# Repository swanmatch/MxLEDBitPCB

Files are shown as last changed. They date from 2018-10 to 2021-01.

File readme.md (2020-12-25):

# 無限の可能性

[Cherry-Mx-Bitboard](https://github.com/ogatatsu/Cherry-Mx-Bitboard)を改変し、
helixを参考にSK6812miniがハマるようにしたものです。

自作キーボード用のプリント基板、１つの基板が１個のスイッチに対応しています。
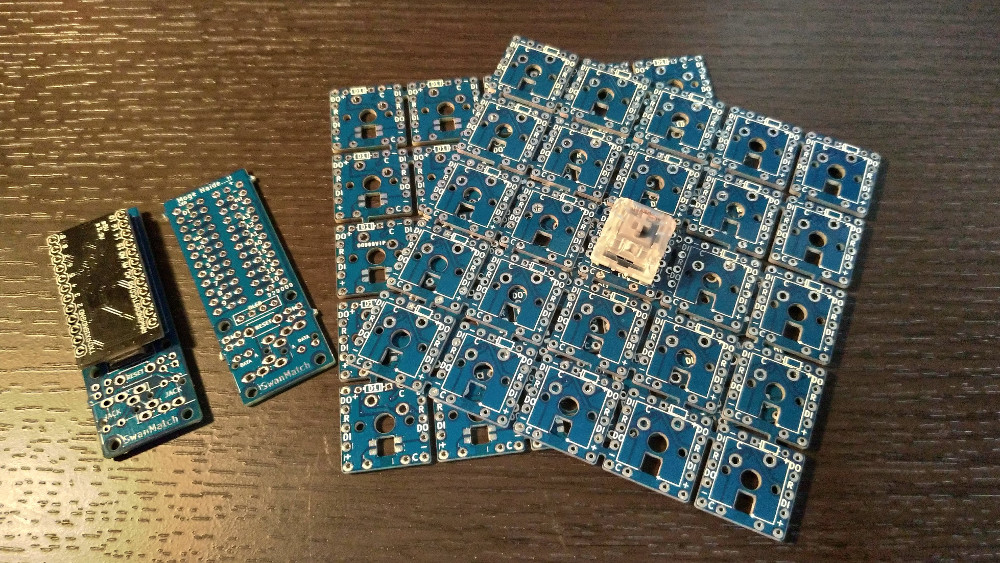
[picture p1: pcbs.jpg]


この基板を使うと、基板設計をしなくてもオリジナル配列のフルカラーバックライトのキーボードが作れます。

たとえば…！

example

詳しくは[こちら](https://swan-match.hatenablog.com/entry/2018/09/15/184923)。

[トッププレートの作り方](https://swanmatch.github.io/topplate_tips)を公開しました。

# Languages
* [Japanese](./readme.md)
* [English](./readme_en.md)
* [French](./readme_fr.md)
* [Russian](./readme_ru.md)
* [Chinese](./readme_zh.md)

## 無限の可能性シリーズ

### ProMicroのおうち

ProMicroのPinを取り出せるようにし、
OLED、リセットスイッチ、分割キーボード向けのTRRS、
そしてマウント用のM2ネジ穴を足したもの。  
TRRSのPinアサインはHelix互換。

### 無限の可能性シリーズ

無限の可能性には複数のシリーズがあり、それぞれ対応するLED,スイッチダイオードが違います。  
以下に仕様をまとめます。

プロジェクト | スイッチ | Kailhソケット利用可否 | LED | スルーホールダイオード | SOD-123 |
-|-|-|-|-|-
Nexus | MX | No | SK6812MINI | Yes | No |
Altana | MX | Yes | SK6812MINI | Yes | No |
Suxen | MX | No | YS-SK6812MINI | Yes | Yes(*) |
Container | MX | Yes | YS-SK6812MINI | Yes | Yes(*) |
Choc | KailhLowProfile | No | YS-SK6812MINI | No | Yes |

(*) スウェンとコンテナでSOD-123を使う場合、スペースの都合で片方のパッドをスルーホールの穴と共有することになるので、少しトリッキーな実装になります。

## 材料例(仕入先)

* 任意にカットしたプレート
  * 2mmアクリル板(遊舎工房さん)  
    3mmアクリル角材とアクリルサンデーなどの接着剤があるとよいです。(ホームセンター)
  * 3Dケース(DMM.make)
  * 5mmダンボール(そのへんから拾ってくるなど。)
* スイッチングダイオード1N4148、SOD-123(TALPKeyboardさん)
* SK6812mini、YS-SK6812MINI-E(遊舎工房さん)
* Kailhソケット(遊舎工房さん、Talpkeyboardさん、Kbdfansさん)
* ウレタンエナメル線(0.35～0.45mmくらいのものがオススメ。ホームセンタなどにもある。ビニル線でも可能ですが溶けちゃったり結構大変)
* TRRSジャック、RESETボタン(秋月電子さん)
* OLED(オプション、遊舎工房さん)
* Promicro(遊舎工房さん、TALPkeyboardさん)
* 各種スペーサー、ネジ(廣杉計器さん、Wilcoさんなど)
* キースイッチ、キーキャップ(お好みに応じて遊舎工房さん、TalpKeyboardさんなど)
* USBケーブル、TRS(3.5mm3極)ケーブル

その他に温度調節はんだごて、テスター、ピンセットなどの工具が必要です。

## Pinアサイン

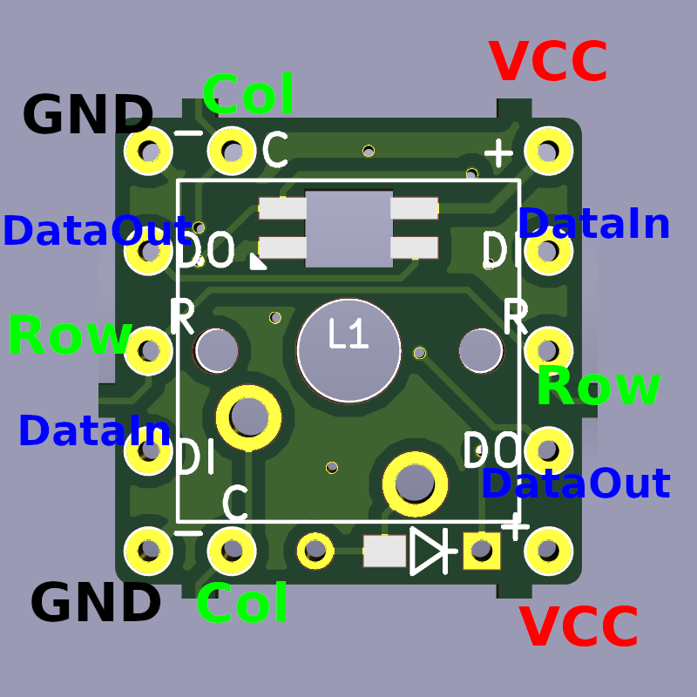
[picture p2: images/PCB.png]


無限の可能性のピン配置は以下の通りです。

* Ｃ: 横線(Col)
* Ｒ: 縦線(Row)
* DI: LED制御信号入力(DataIn)
* DO: LED制御信号出力(DataOut)
* －: グランド(LED用)
* ＋: VCC(LED用5V)

写真の例はSuxenですが、ほかもだいたい似たような感じです。

## 組立手順

1. SK6812miniをはんだ付けします。  
  温度調節はんだごてで220℃くらいではんだ付けしてください。  
  もたもたしていると壊れます。  
  はんだも融点200℃以下の低温はんだを使ってください。
2. ダイオードをはんだ付けします。
3. トッププレートにスイッチをはめて、裏に無限の可能性をはめてスイッチの足をはんだ付けします。(Altana,Containerはソケット)  
  このとき2mmアクリル板を使う場合は、スイッチが抜けてしまうのを防ぐため、
  プレート裏面のスイッチ脇に3mmアクリル角材をアクリル接着剤などでくっつけておくこといいです。
4. 自身の組みたいキーボードのキーマトリックスに合わせ、横線(Col)と縦線(Row)を配線します。
5. 全ての「－」と「＋」をつなげる。
6. LEDの光らせたい順番にDIからDOに数珠つなぎに配線していきます。
  一個目DO→二個目DI→二個目DO→三個目DI…
7. TRRSJACKとRESETスイッチをはんだ付けします。
8. OLEDソケットをはんだ付けします。
9. 任意のピンの横の穴からColとRow、LED(DO)、GND、VCCをそれぞれ無限の可能性に対して配線します。
10. Promicroをソケットにはんだ付けします。  
  (コンスルーを使ってもいいですが、もげたらソケットごと交換したほうが安上がり。)
11. お好みに合わせてファームウェアを作成して書き込んで完成。  
  ファームウェアは[QMK_Firmware](https://github.com/qmk/qmk_firmware)を使うととても簡単です。  
  参考: [自作キーボードのファームウェアを用意する手段3種類](https://skyhigh-works.hatenablog.com/entry/2018/10/09/120909)

## 配線例

例えばSuxenで下記のような配列の場合、以下のような配線になります。  
ウレタンエナメル線(UEW)は被膜を剥がすのが結構大変なので、
ショートの可能性が少ない隣り合う基板間の配線は、
切り落としたダイオードの足がオススメです。  

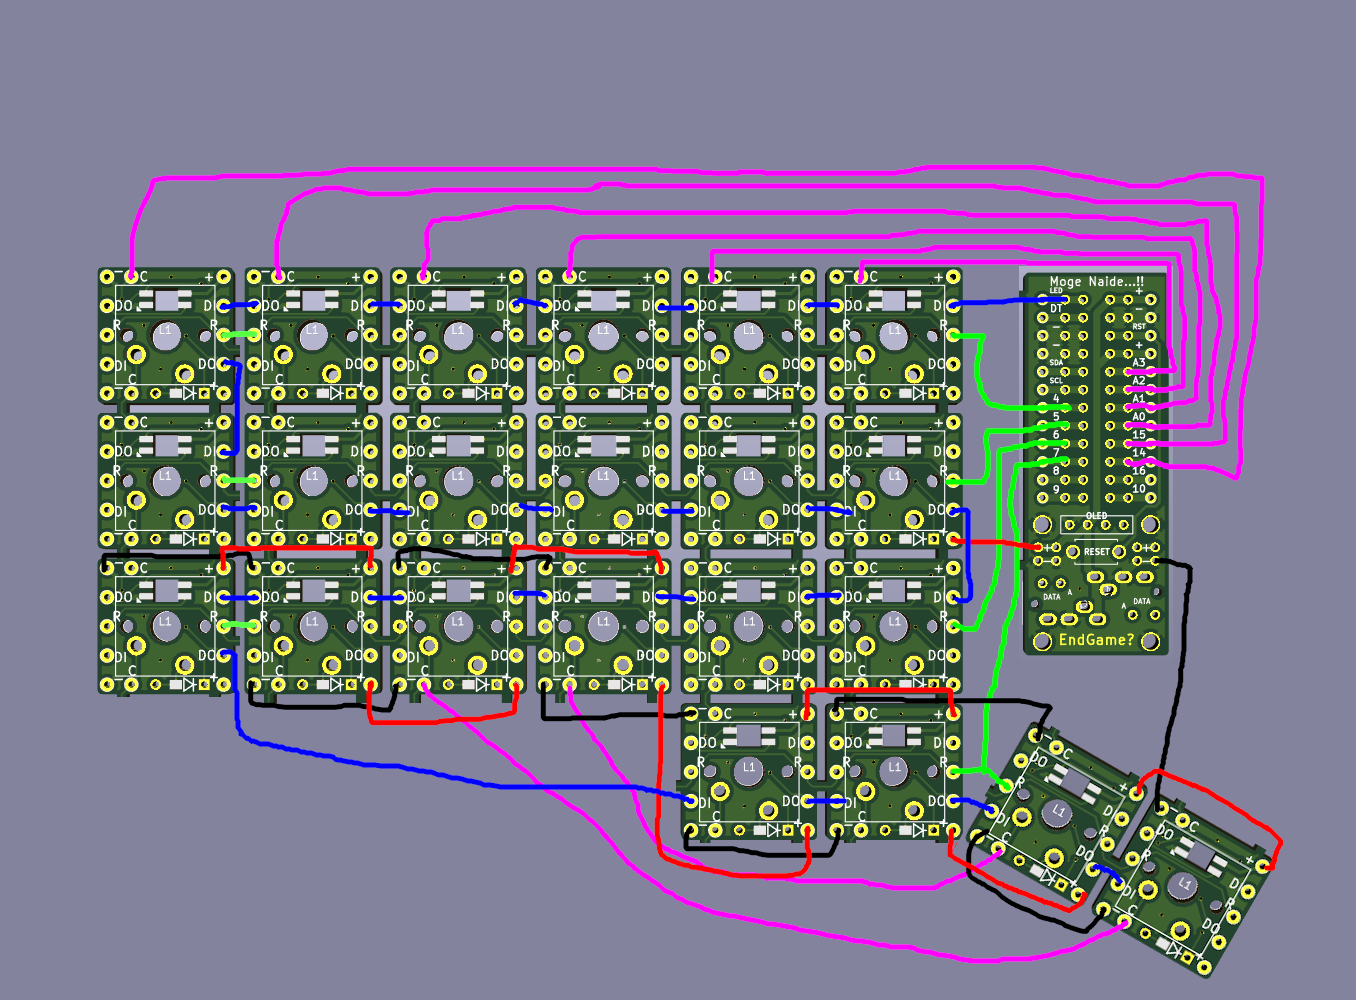
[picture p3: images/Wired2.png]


### 注意事項

* Altana、ContainerはKailhソケットを使ってスイッチを交換できるバージョンです。
* Suxen、ContainerはYS-SK6812MINIに対応していて、LEDの欠けている足をPCBの三角のシルクに合わせて実装してください。
* もしも万が一やんごとなき事情で、どうしてもLEDを光らせる必要がない場合、
  ColとRowだけ配線すればキーボードとして機能します。[配線例](./images/Wired.png)
* 国内でよく採用されている、サンドイッチマウントのキーボードの場合、
  トッププレートとボトムプレートをスペーサーで配置しますが、
  無限の可能性の場合キーの間にスペーサーが入る隙間がありません。
  キーの外側にネジ穴を設けてください。
* 「おうち」は、先にPromicroをはんだ付けしてしまうと、
  無限の可能性側と配線する際に、ハンダがホールからもれて、
  Promicro本体の部品をショートさせてしまう場合があります。  
  Promicroは最後にはんだ付けするようにしてください。

## 終わりに

この基板を使ってキーボードを組んだ際にはぜひ[@swan_match](https://twitter.com/swan_match)までご一報ください。

あなたのEndGameを応援しています！！

## Licence

https://creativecommons.org/licenses/by/4.0/

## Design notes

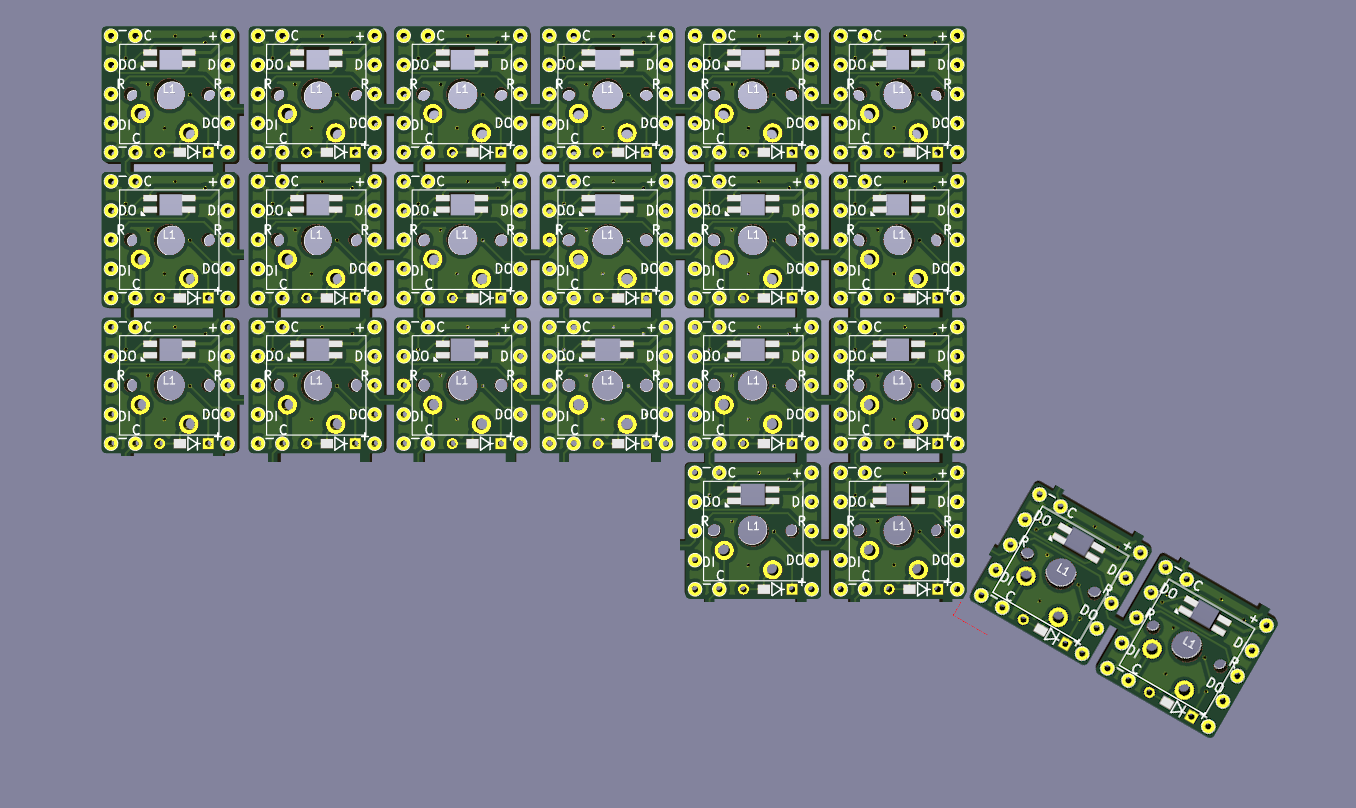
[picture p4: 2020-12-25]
images/Wired.png

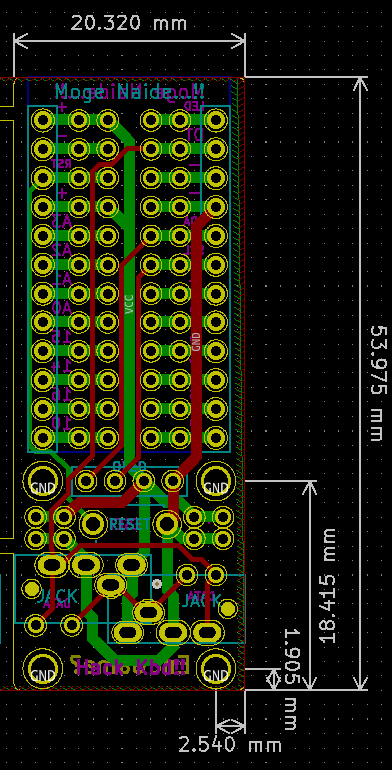
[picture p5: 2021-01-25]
images/home-size.png

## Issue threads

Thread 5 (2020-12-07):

difference between altana, choc, container, nexus, suxen

marcinliebiediew, 2020-12-07:
Hi!

I'm a bit puzzled about choosing the right version for my project.
In your repository, I could find the following switch PCB KiCAD projects:
- altana
- choc
- container
- nexus
- suxen

After reading `readme_en.md` I assume altana can be used with kailh switches, whereas nexus cannot?

I did try to compare these two in KiCAD and I can spot many differences but I don't understand why there are differences.
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
(nexus on the left, altana on the right)

Could you please explain what are the differences between these 5 versions?

Which version should I pick for Cherry MX switches? And which one for Kailh switches?

Cheers!

swanmatch, 2020-12-07:
I'm sorry I didn't update the document in time.
Each project differs in its corresponding LED and whether or not Kailh's switch socket can be used.

Project | Switch | Socket | LED
-|-|-|-
Nexus | MX | No | SK6812MINI
Altana | MX | Yes | SK6812MINI
Suxen | MX | No | YS-SK6812MINI
Container | MX | Yes | YS-SK6812MINI
Choc | KailhLowProfile | No | YS-SK6812MINI

* [YS-SK6812MINI](https://yushakobo.jp/shop/ys-sk6812mini-e/)
* [SK6812MINI](https://yushakobo.jp/shop/sk6812mini-10/)
* [Kailh Socket](https://kbdfans.com/products/mechanical-keyboard-switches-kailh-pcb-socket)

kailh's MX compatible switches (such as Kailh Pro Burgundy) can be used outside of Choc.
KailhLowProfile can only be used with Choc.

marcinliebiediew, 2020-12-07:
Beautiful, I wasn't sure what Kailh socket was, thank you for the link.
Everything is clear, many thanks for the swift reply and your great work!

marcinliebiediew, 2020-12-07:
Sorry, two questions actually :))

1. What makes Nexus not compatible with the Kailh socket, and what makes Altana compatible with the socket?
From KiCAD scheme I understand Nexus has holes for the switch legs:
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
whereas Altana does not:
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
But why does this make a difference in incompatibility?
In my mind, the pins coming out from the switch, are supposed to go through the PCB no matter what:
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
But maybe on that picture ([source](https://imgur.com/a/3xqx0M3)), the Kailh socket is mounted on another side than originally planned in your project?
Correct me if I'm wrong, but it seems to me that having no holes for the switch legs, would require precise measurement of the distance between the top-plate, and the PCB (which I perceive as unwanted)?
I hope I didn't mix something up...

2. Can you please outline the differences in performance between YS-SK6812MINI and SK6812MINI, if any?

swanmatch, 2020-12-08:
1. When you use the Kailh socket, which needs a specific design, you cannot  share.
  Nexus has plated holes, and Altana? has mechanical holes.
  It's even easier to understand if you watch 3D viewer.
2. Ys-sk6812mini has tabs, so it's easy to solder it.

Closed 2020-12-08.

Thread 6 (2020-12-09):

Feature Request: SOD-123

fi0, 2020-12-09:
Thank you for your great work!
Can you add a diode footprint that supports both through hole and SOD-123 please?

swanmatch, 2020-12-10:
Choc does not support through holes due to space limitations, only SOD123.
suxen and Container have pads for SOD123, but due to space limitations, one pad is shared with TH, which makes the implementation a bit trickier.
Basically, a through-hole diode is recommended because the legs of the cut diode can be used for wiring.

Project | Switch | Socket | LED | THDiode | SOD-123 |
-|-|-|-|-|-
Nexus | MX | No | SK6812MINI | Yes | No |
Altana | MX | Yes | SK6812MINI | Yes | No |
Suxen | MX | No | YS-SK6812MINI | Yes | Yes |
Container | MX | Yes | YS-SK6812MINI | Yes | Yes |
Choc | KailhLowProfile | No | YS-SK6812MINI | No | Yes |

fi0, 2020-12-10:
Thank you for the explanation!! 😄

Closed 2020-12-10.

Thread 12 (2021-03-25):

Feature request: mountable MxLEDBitPCB

fi0, 2021-03-25:
Just an idea ..
2 tiny mounting holes will be useful for hand wired dactyl-like keyboards so that we don't need to use hot glue.

This is something similar on the NeoKey Socket Breakout.

swanmatch, 2021-04-17:
@fi0

Sorry for the late reply!

Is this the hole you're referring to?
I've already drilled those holes on all the boards!

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

Closed 2021-06-16.

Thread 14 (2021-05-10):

SK6812 solder side ?

coliss86, 2021-05-10:
Hi,

could you tell me if the led is in the correct position according to the following photos ?
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

If so, the led is facing the bottom. I don't understand why it isn't oriented to the top of the keyboard in order to glow through the switch ?

Regards

coliss86, 2021-05-10:
ok, I found my error : I'm using SK6812 MINI**-E** instead of SK6812 MINI :(

swanmatch, 2021-05-11:
@coliss86
Please refer to the following.
Photo PCB looks Altana.

project | switch | Kailh socket availability | led | Through-hole diode | SOD-123
--- | --- | --- | --- | --- | ---
Nexus | MX | No | SK6812MINI | Yes | No
Altana | MX | Yes | SK6812MINI | Yes | No
Suxen | MX | No | YS-SK6812MINI | Yes | Yes (*)
Container | MX | Yes | YS-SK6812MINI | Yes | Yes (*)
Choc | KailhLowProfile | No | YS-SK6812MINI | No | Yes

fi0, 2021-06-16:
@swanmatch is YS-SK6812MINI the same as SK6812MINI-E?

swanmatch, 2021-06-16:
@fi0 Yes!

safijari, 2022-02-04:
So I should have gotten Container instead of Altana ... Dang it

Closed 2021-05-10.

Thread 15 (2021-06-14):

where to find the pcb used to mount the mcu

pathnirvana, 2021-06-14:
this is question rather than a issue.
anyone know where to find the pcb used to mount the mcu in the wiring diagram in the readme?

l4u, 2021-06-16:
https://github.com/swanmatch/MxLEDBitPCB/tree/master/MxLEDBitPCB-promicro

pathnirvana, 2021-06-17:
Many thanks @l4u
by the way when I was printing the container.zip via jclpcb few days ago they were rejecting the order mentioning that breakout tabs were too small (had to be at least 4mm to prevent the panels from coming apart during production). However after I mentioned that my previous order of altana was printed without any issues they agreed to proceed with the order. Just FYI

swanmatch, 2022-02-09:
@l4u Thanks for the follow!
@pathnirvana I hope everything goes well for you.

Closed 2022-02-09.

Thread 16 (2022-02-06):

Container spacing issue

christrotter, 2022-02-06:
I submitted the container.zip (the one from this repo - I did not make it) to JLCPCB and got this audit failure:
```
Dear the spacing from slot to slot and slot to board edge are too small which will cause the board broken easily,please kindly increase it to 4mm at least.Thanks.
```
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

I'm guessing they mean the connectors?
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

I have asked for clarity in the mean time...if I can figure out what software to use, I'll try and submit a PR to fix once they tell me the specific problem.

christrotter, 2022-02-07:
My exact message, accompanied by that picture with the red arrrow...
```
For clarity - this panel is intended to be broken apart into 25 pieces for use.  Is your concern rather for the manufacturing process having breakages?
In the attached - is the red arrow pointing at what you want increased to at least 4mm?
```

And their response...
```
Dear Sir,
Yes,please add the indicated spacing to 4 mm at least.
```

So I'm gonna go with they want those little board-to-board connection points to be 4mm.  I will do some research on what software to use to edit the files...

christrotter, 2022-02-07:
So Kicad seems to be what is used, and I have no idea what I'm doing here.  I might have to go the amoeba royale v2.0 route instead. :(

khominhvi, 2022-02-07:
I had the same issue with JLCPCB.

In another post, which seems to have disappeared, recommended another manufacturer; elecrow, which is what I used to have the pcbs manufactured.

christrotter, 2022-02-07:
Interesting - I checked them out @khominhvi , do you recall what order settings you used?  Elecrow seems to have less options.   Like no panel settings...

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

khominhvi, 2022-02-07:
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

christrotter, 2022-02-07:
You are a champ, awesome, gonna give it a shot.

christrotter, 2022-02-08:
I ended up ordering Amoeba Royale's from JCLPCB and the Container's from Elecrow.  Will post back results to this issue.

It might be worthwhile updating the readme with a section on ordering, I'd be happy to contribute to that.

swanmatch, 2022-02-09:
@christrotter @khominhvi Thank you for your interest.(and sorry for late reply...)
I am aware of the design rules of JLCPCB that will be played by it.
I just can't easily fold it by hand when I unfold the solid.
I order from Elecrow all the time and have manufactured thousands of them and have never been rejected.
Thanks

swanmatch, 2022-02-09:
FYI @christrotter
https://github.com/swanmatch/MxLEDBitPCB/issues/15#issuecomment-863041554

christrotter, 2022-02-09:
@swanmatch Thanks!  If you'd like I could submit a PR with some 'ordering help' in the english readme, might help others in future.

swanmatch, 2022-02-28:
@christrotter That's a great suggestion for me!

christrotter, 2022-02-28:
Made a PR for you! https://github.com/swanmatch/MxLEDBitPCB/pull/17

Closed 2024-01-16.

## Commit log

2018-07-27 first orderd
    [Cherry Mx Bitboard.kicad_pcb, Cherry Mx Bitboard.sch]
2018-07-28 tmp remove readme
    [Cherry Mx Bitboard.kicad_pcb, Cherry Mx Bitboard.sch]
2018-07-30 second ordered
    [Cherry Mx Bitboard-B.Cu.gbl, Cherry Mx Bitboard-B.Mask.gbs, Cherry Mx Bitboard-B.SilkS.gbo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]
2018-09-18 git add suruno wasureta....
    [MxLEDBit-2018-09-12-22-51-45.sch, MxLEDBit.kicad_pcb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]
2018-10-17 garber split
    [MxLEDBit-2018-09-12-22-51-45.sch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]
2018-11-04 submodule deinit
    [MxLEDBit (コピー).kicad_pcb, MxLEDBit-2018-09-12-22-51-45.sch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]
2019-01-09 git is difficult for me...
    [MxLEDBit (コピー).kicad_pcb, MxLEDBit-2018-09-12-22-51-45.sch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]
2019-04-03 nexus and altana
    [MxLEDBit-B.Cu.gbl, MxLEDBit-B.Mask.gbs, MxLEDBit-B.SilkS.gbo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]
2020-02-29 add YS-SK6812MINIver and choc
    [choc.kicad_pcb, choc.sch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]
2020-03-09 update large silk and forgot diode
    [choc.kicad_pcb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]
2021-01-12 fix silk
    [choc.kicad_pcb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]
2021-01-25 add promicro hole position image.
    [choc-B_Cu.gbl, choc-B_Mask.gbs, choc-B_SilkS.gbo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]
